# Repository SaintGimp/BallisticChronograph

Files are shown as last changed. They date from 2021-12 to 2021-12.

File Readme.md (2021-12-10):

This project is heavily based on https://github.com/td0g/ballistic_chronograph_mk2 but modified to use phototransistors rather than photodiodes, mostly because components for the boost converter in the original design are really hard to source right now, and I also wanted to optimize for my own use cases.

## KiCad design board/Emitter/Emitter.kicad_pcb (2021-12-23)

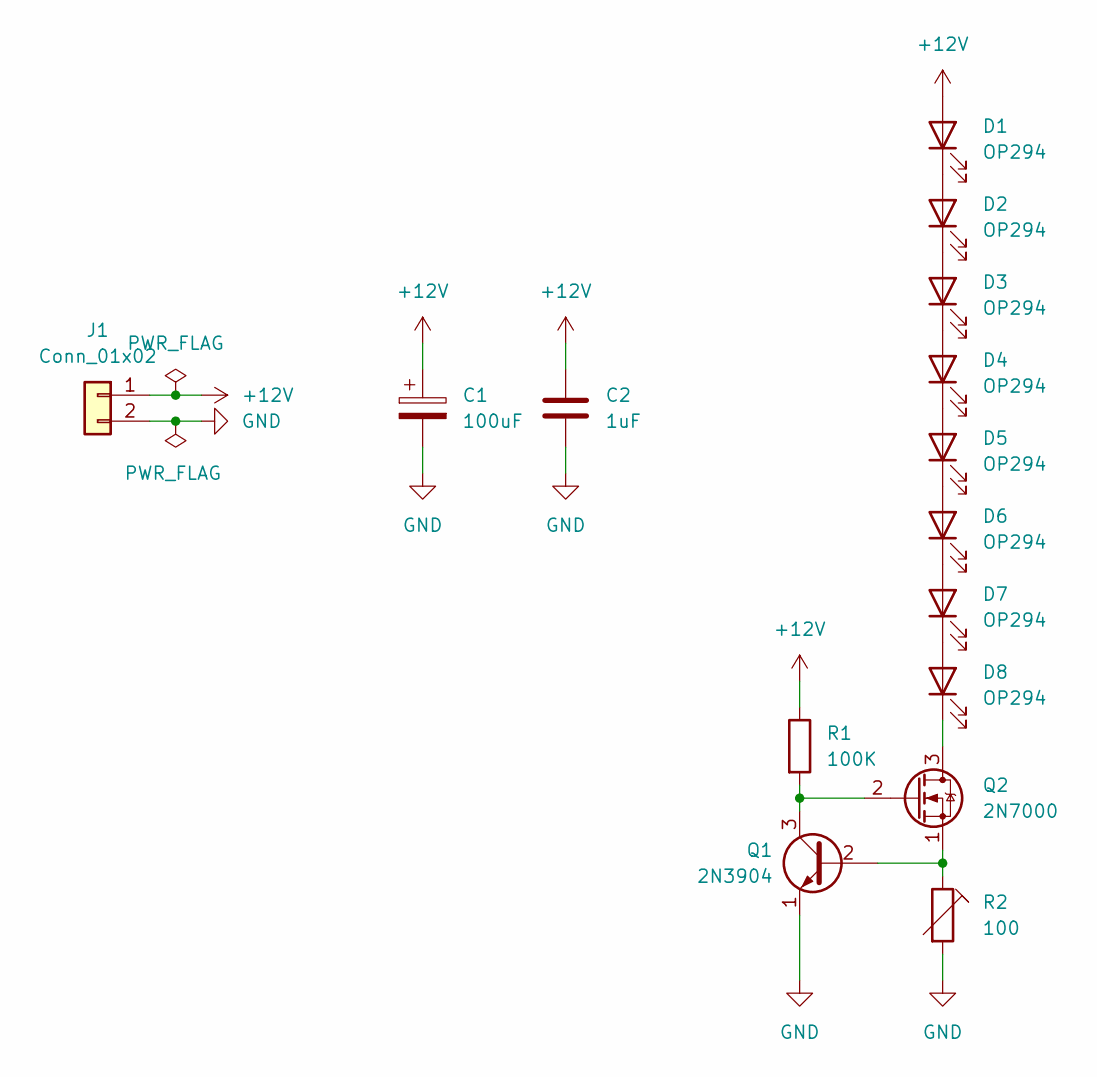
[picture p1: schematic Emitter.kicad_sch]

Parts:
C1: 100uF; CP_Radial_D6.3mm_P2.50mm
C2: 1uF; C_Disc_D4.7mm_W2.5mm_P5.00mm
D1, D2, D3, D4, D5, D6, D7, D8: OP294; LED_D5.0mm_IRGrey
J1: Conn_01x02; TerminalBlock_TE_282834-2_1x02_P2.54mm_Horizontal
Q1: 2N3904; TO-92_Inline
Q2: 2N7000; TO-92_Inline
R1: 100K; R_Axial_DIN0207_L6.3mm_D2.5mm_P7.62mm_Horizontal
R2: 100; Potentiometer_Bourns_3296W_Vertical

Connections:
+12V: C1.1, C2.1, D1.2 (A), J1.1, R1.1
GND: C1.2, C2.2, J1.2, Q1.1 (E), R2.2
unnamed: D1.1 (K), D2.2 (A)
unnamed: D2.1 (K), D3.2 (A)
unnamed: D3.1 (K), D4.2 (A)
unnamed: D4.1 (K), D5.2 (A)
unnamed: D5.1 (K), D6.2 (A)
unnamed: D6.1 (K), D7.2 (A)
unnamed: D7.1 (K), D8.2 (A)
unnamed: D8.1 (K), Q2.3 (D)
unnamed: Q1.2 (B), Q2.1 (S), R2.1
unnamed: Q1.3 (C), Q2.2 (G), R1.2

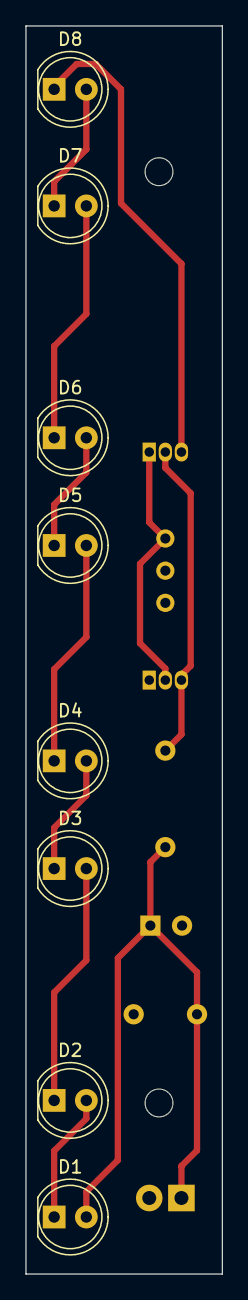
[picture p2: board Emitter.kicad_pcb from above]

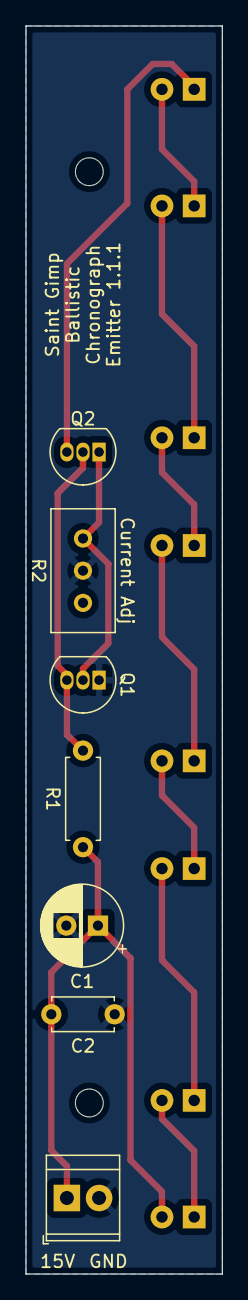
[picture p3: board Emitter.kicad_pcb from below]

Board: 2 copper layers, 15.5 x 98.5 mm, 15 parts (7 on the bottom side), 12 nets.

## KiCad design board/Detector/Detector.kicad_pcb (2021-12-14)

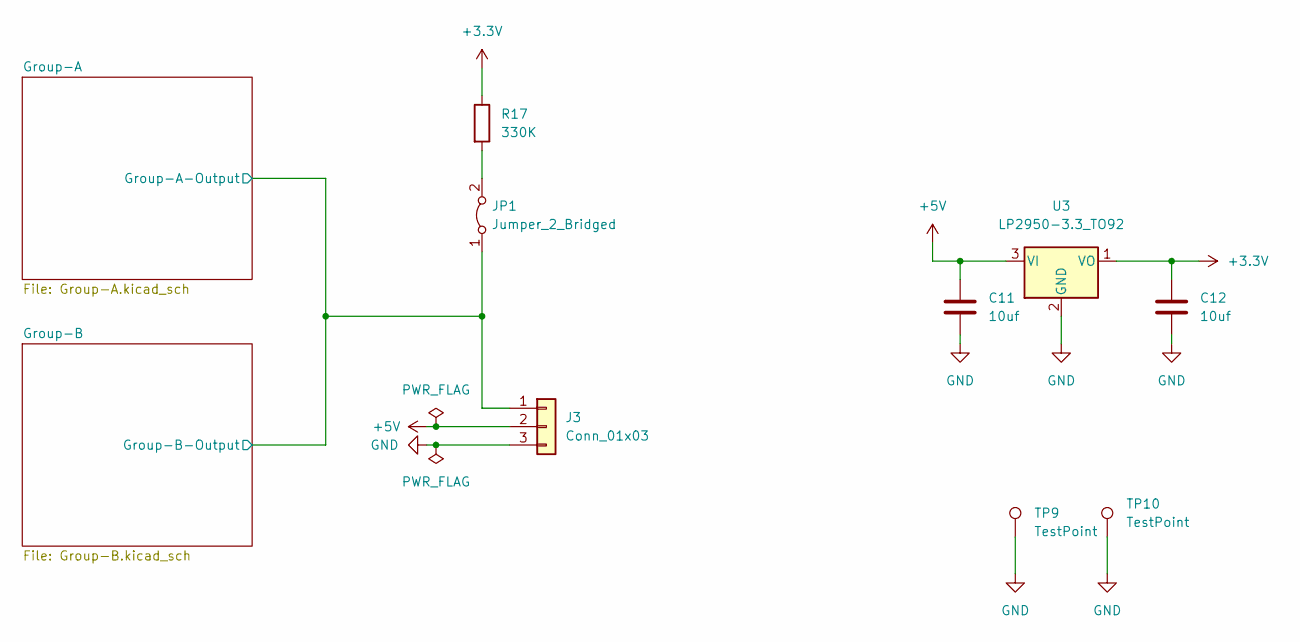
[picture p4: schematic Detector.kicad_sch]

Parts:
C11, C12: 10uf; C_1206_3216Metric_Pad1.33x1.80mm_HandSolder
J3: Conn_01x03; TerminalBlock_TE_282834-3_1x03_P2.54mm_Horizontal
JP1: Jumper_2_Bridged; SolderJumper-2_P1.3mm_Bridged_Pad1.0x1.5mm
R17: 330K; R_0805_2012Metric_Pad1.20x1.40mm_HandSolder
TP9, TP10: TestPoint; PinHeader_1x01_P2.54mm_Vertical
U3: LP2950-3.3_TO92; TO-92_Inline

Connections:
+3V3: C12.1, R17.1, U3.1 (VO); also elsewhere on the board
+5V: C11.1, J3.2, U3.3 (VI)
/Group-A/Group-A-Output: J3.1, JP1.1 (A); also elsewhere on the board
GND: C11.2, C12.2, J3.3, TP9.1, TP10.1, U3.2 (GND); also elsewhere on the board
unnamed: JP1.2 (B), R17.2

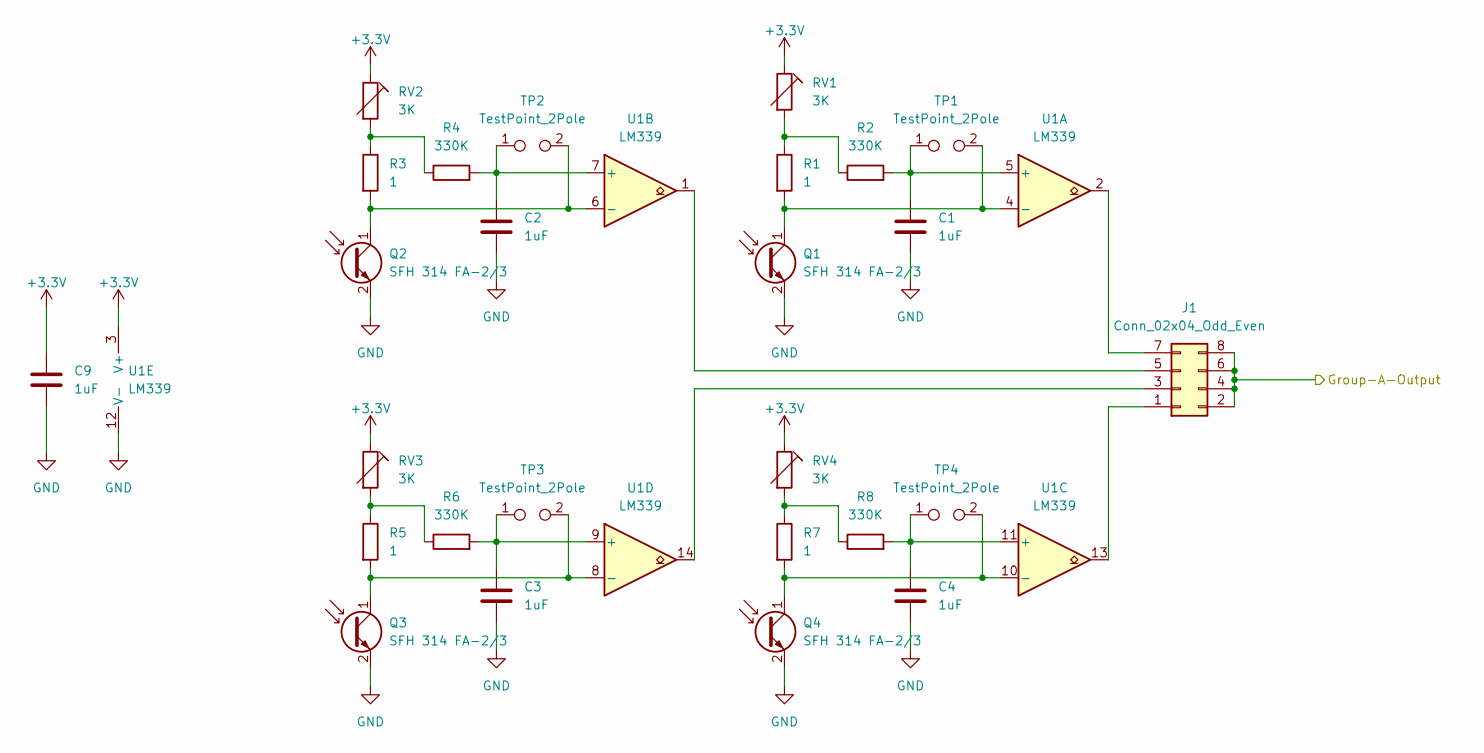
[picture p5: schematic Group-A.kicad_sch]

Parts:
C1, C2, C3, C4, C9: 1uF; C_0805_2012Metric_Pad1.18x1.45mm_HandSolder
J1: Conn_02x04_Odd_Even; PinHeader_2x04_P2.54mm_Vertical
Q1, Q2, Q3, Q4: SFH 314 FA-2/3; LED_D3.0mm_IRBlack
R1, R3, R5, R7: 1; R_0805_2012Metric_Pad1.20x1.40mm_HandSolder
R2, R4, R6, R8: 330K; R_0805_2012Metric_Pad1.20x1.40mm_HandSolder
RV1, RV2, RV3, RV4: 3K; 3362P_1
TP1, TP2, TP3, TP4: TestPoint_2Pole; PinHeader_1x02_P2.54mm_Vertical
U1: LM339; TSSOP-14_4.4x5mm_P0.65mm

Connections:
+3V3: C9.1, RV1.1, RV2.1, RV3.1, RV4.1, U1.3 (V+); also elsewhere on the board
/Group-A/Group-A-Output: J1.2, J1.4, J1.6, J1.8; also elsewhere on the board
GND: C1.2, C2.2, C3.2, C4.2, C9.2, Q1.2 (E), Q2.2 (E), Q3.2 (E), Q4.2 (E), U1.12 (V-); also elsewhere on the board
unnamed: C1.1, R2.2, TP1.1, U1.5 (+)
unnamed: C2.1, R4.2, TP2.1, U1.7 (+)
unnamed: C3.1, R6.2, TP3.1, U1.9 (+)
unnamed: C4.1, R8.2, TP4.1, U1.11 (+)
unnamed: J1.1, U1.13
unnamed: J1.3, U1.14
unnamed: J1.5, U1.1
unnamed: J1.7, U1.2
unnamed: Q1.1 (C), R1.2, TP1.2, U1.4 (-)
unnamed: Q2.1 (C), R3.2, TP2.2, U1.6 (-)
unnamed: Q3.1 (C), R5.2, TP3.2, U1.8 (-)
unnamed: Q4.1 (C), R7.2, TP4.2, U1.10 (-)
unnamed: R1.1, R2.1, RV1.2
unnamed: R3.1, R4.1, RV2.2
unnamed: R5.1, R6.1, RV3.2
unnamed: R7.1, R8.1, RV4.2

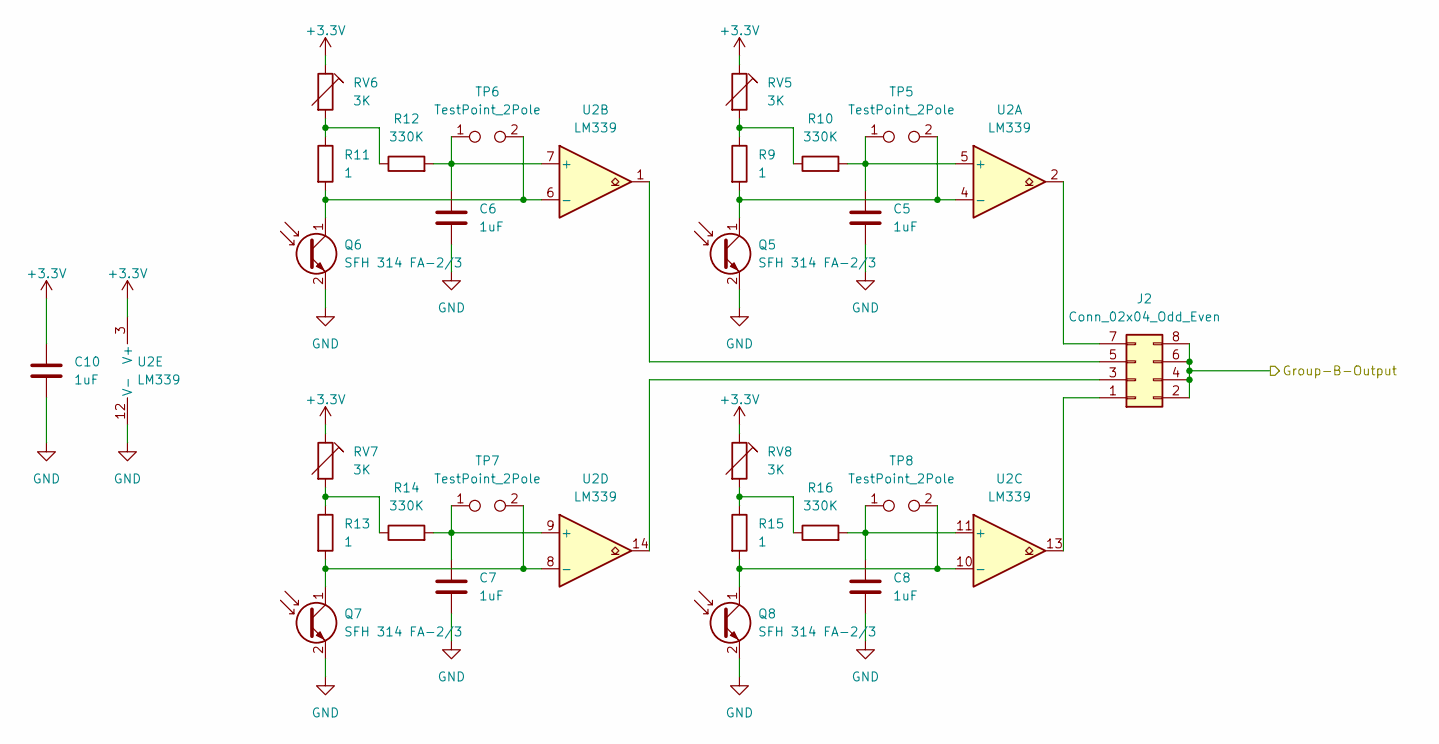
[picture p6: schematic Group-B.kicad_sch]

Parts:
C5, C6, C7, C8, C10: 1uF; C_0805_2012Metric_Pad1.18x1.45mm_HandSolder
J2: Conn_02x04_Odd_Even; PinHeader_2x04_P2.54mm_Vertical
Q5, Q6, Q7, Q8: SFH 314 FA-2/3; LED_D3.0mm_IRBlack
R9, R11, R13, R15: 1; R_0805_2012Metric_Pad1.20x1.40mm_HandSolder
R10, R12, R14, R16: 330K; R_0805_2012Metric_Pad1.20x1.40mm_HandSolder
RV5, RV6, RV7, RV8: 3K; 3362P_1
TP5, TP6, TP7, TP8: TestPoint_2Pole; PinHeader_1x02_P2.54mm_Vertical
U2: LM339; TSSOP-14_4.4x5mm_P0.65mm

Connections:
+3V3: C10.1, RV5.1, RV6.1, RV7.1, RV8.1, U2.3 (V+); also elsewhere on the board
/Group-A/Group-A-Output: J2.2, J2.4, J2.6, J2.8; also elsewhere on the board
GND: C5.2, C6.2, C7.2, C8.2, C10.2, Q5.2 (E), Q6.2 (E), Q7.2 (E), Q8.2 (E), U2.12 (V-); also elsewhere on the board
unnamed: C5.1, R10.2, TP5.1, U2.5 (+)
unnamed: C6.1, R12.2, TP6.1, U2.7 (+)
unnamed: C7.1, R14.2, TP7.1, U2.9 (+)
unnamed: C8.1, R16.2, TP8.1, U2.11 (+)
unnamed: J2.1, U2.13
unnamed: J2.3, U2.14
unnamed: J2.5, U2.1
unnamed: J2.7, U2.2
unnamed: Q5.1 (C), R9.2, TP5.2, U2.4 (-)
unnamed: Q6.1 (C), R11.2, TP6.2, U2.6 (-)
unnamed: Q7.1 (C), R13.2, TP7.2, U2.8 (-)
unnamed: Q8.1 (C), R15.2, TP8.2, U2.10 (-)
unnamed: R9.1, R10.1, RV5.2
unnamed: R11.1, R12.1, RV6.2
unnamed: R13.1, R14.1, RV7.2
unnamed: R15.1, R16.1, RV8.2

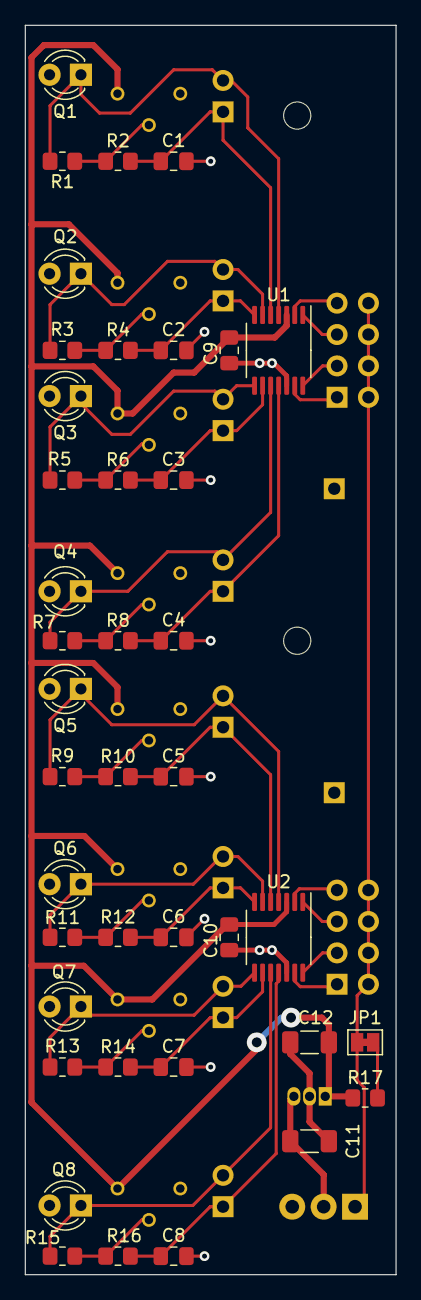
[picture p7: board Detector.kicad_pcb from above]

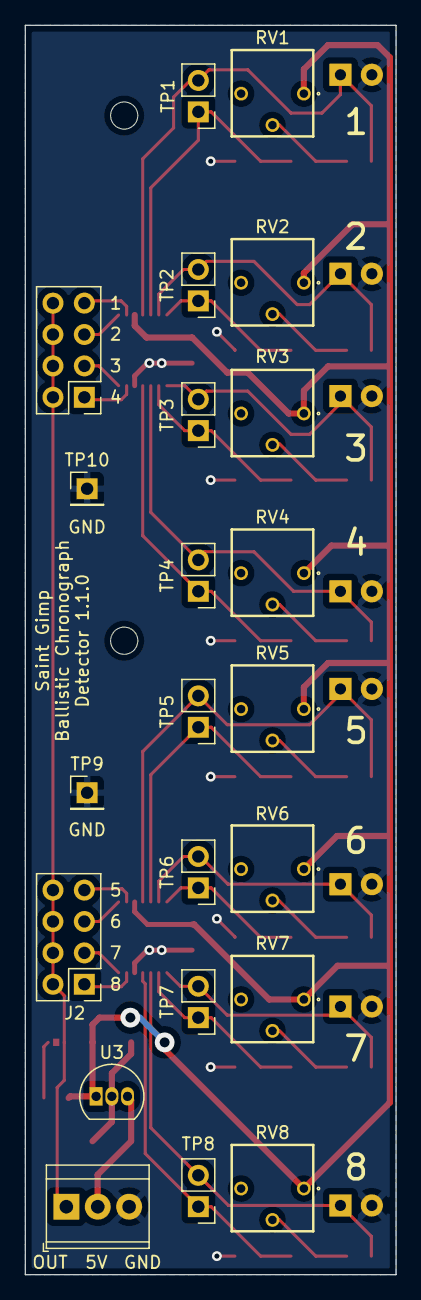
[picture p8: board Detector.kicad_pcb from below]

Board: 2 copper layers, 30.0 x 101.1 mm, 62 parts (22 on the bottom side), 37 nets.

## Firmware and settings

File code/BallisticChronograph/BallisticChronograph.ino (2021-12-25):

#include <splash.h>
#include <Adafruit_SH110X.h>

// OLED FeatherWing buttons map to different pins depending on board:
#if defined(ESP8266)
  #define BUTTON_A  0
  #define BUTTON_B 16
  #define BUTTON_C  2
#elif defined(ESP32) && !defined(ARDUINO_ADAFRUIT_FEATHER_ESP32S2)
  #define BUTTON_A 15
  #define BUTTON_B 32
  #define BUTTON_C 14
#elif defined(ARDUINO_STM32_FEATHER)
  #define BUTTON_A PA15
  #define BUTTON_B PC7
  #define BUTTON_C PC5
#elif defined(TEENSYDUINO)
  #define BUTTON_A  4
  #define BUTTON_B  3
  #define BUTTON_C  8
#elif defined(ARDUINO_NRF52832_FEATHER)
  #define BUTTON_A 31
  #define BUTTON_B 30
  #define BUTTON_C 27
#else // 32u4, M0, M4, nrf52840, esp32-s2 and 328p
  #define BUTTON_A  9
  #define BUTTON_B  6
  #define BUTTON_C  5
#endif

const int PULSE1_PIN = 9;
const int PULSE2_PIN = 11;

const int millimetersBetweenSensors = 426;

volatile long time1 = 0;
volatile long time2 = 0;

int numberOfEvents = 0;

Adafruit_SH1107 display = Adafruit_SH1107(64, 128, &Wire);

void setup() {
  Serial.begin(115200);

  pinMode(LED_BUILTIN, OUTPUT);
  pinMode(PULSE1_PIN, INPUT);
  pinMode(PULSE2_PIN, INPUT);
  pinMode(BUTTON_A, INPUT_PULLUP);
  pinMode(BUTTON_B, INPUT_PULLUP);
  pinMode(BUTTON_C, INPUT_PULLUP);

  attachInterrupt(digitalPinToInterrupt(PULSE1_PIN), pulse1_falling, FALLING);
  attachInterrupt(digitalPinToInterrupt(PULSE2_PIN), pulse2_falling, FALLING);

  display.begin(0x3C, true);
  display.display();
  delay(1000);
  display.clearDisplay();
  display.setTextSize(2);
  display.setTextColor(SH110X_WHITE);
  display.setRotation(1);

  display.println("Ready...");
  display.display();
}

void loop() {
  if (!digitalRead(BUTTON_C)) {
    numberOfEvents = 0;

    display.clearDisplay();
    display.setCursor(0,0);
    display.println("Ready...");
    display.display();
  }

  if (time1 > 0 && time2 == 0 || time1 == 0 && time2 > 0)
  {
    digitalWrite(LED_BUILTIN, HIGH);

    // Reset after some time if only one sensor triggered
    long currentTime = micros();
    if (time1 > 0 && currentTime - time1 > 2000000)
    {
      time1 = 0;
    }
    else if (time2 > 0 && currentTime - time2 > 2000000)
    {
      time2 = 0;
    }
  }
  else
  {
    digitalWrite(LED_BUILTIN, LOW);
  }
  
  if (time1 > 0 && time2 > 0)
  {
    numberOfEvents++;
    
    long intervalInMicros = abs(time1 - time2);
    float speedInMetersPerSecond = (millimetersBetweenSensors / 1000.0f) / (intervalInMicros / 1000000.0f);
    display.clearDisplay();
    display.setCursor(0,0);
    display.print(intervalInMicros);
    display.println(" us");
    display.print(speedInMetersPerSecond);
    display.println(" m/s");
    display.print(numberOfEvents);
    display.println(" events");
    display.display();

    Serial.print(speedInMetersPerSecond);
    Serial.println(" m/s");

    time1 = 0;
    time2 = 0;
  }
}

void pulse1_falling() {
  if (time1 == 0) {
    time1 = micros();
  }
}

void pulse2_falling() {
  if (time2 == 0) {
    time2 = micros();
  }
}

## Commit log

2021-11-24 Detector board checkpoint
    [Detector.kicad_pcb, Detector.kicad_sch, Group-A.kicad_sch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]
2021-11-25 Complete layout with top pour
    [Detector.kicad_pcb, Detector.kicad_sch]
2021-11-26 Final version of detector and gerbers
    [Detector-B_Cu.gbl, Detector-B_Mask.gbs, Detector-B_Paste.gbp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]
2021-11-26 First rev of emitter
    [Emitter.kicad_pcb, Emitter.kicad_sch]
2021-11-26 Emitter gerbers
    [Emitter-B_Cu.gbr, Emitter-B_Mask.gbr, Emitter-B_Paste.gbr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]
2021-12-10 Fix the order of jumper links
    [Detector.kicad_pcb, Group-A.kicad_sch, Group-B.kicad_sch]
2021-12-10 Increase led and phototransistor spacing to better handle angled holes
    [Detector.kicad_pcb, Emitter.kicad_pcb]
2021-12-10 Adjust values
    [Detector.kicad_sch, Emitter.kicad_sch, Group-A.kicad_sch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]
2021-12-10 Detector changes to better control overall bias level
    [Detector.kicad_pcb, Detector.kicad_sch, Emitter.kicad_pcb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]
2021-12-14 Changed connectors, 3D models, added test points
    [Detector.kicad_pcb, Detector.kicad_sch, Emitter.kicad_pcb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]
2021-12-14 Updated gerbers
    [Detector-B_Cu.gbl, Detector-B_Mask.gbs, Detector-B_Paste.gbp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]
2021-12-23 Update silkscreen on emitter
    [Emitter-B_Cu.gbr, Emitter-B_Mask.gbr, Emitter-B_Paste.gbr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]
2021-12-25 Initial prototype code using Featherwing OLED
2022-06-14 Reduce sensitivity so we don't trigger on dust
    [Detector.kicad_sch, Group-A.kicad_sch, Group-B.kicad_sch]
